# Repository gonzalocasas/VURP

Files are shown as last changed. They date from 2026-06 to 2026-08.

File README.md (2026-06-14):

# 🤖 VURP — Valentin's Ultimate Rover Project

A WiFi-controlled tracked rover, built together by Valentin and Papa.

**Goal:** Learn electronics & coding while building something genuinely cool — a
tank-tread rover you can drive from a phone or laptop browser, with sensors and a
glowing LED ring.

> 🚀 **Start here:** [SETUP.md](SETUP.md) — set up VS Code + PlatformIO and upload
> our first program. Code lives in [src/main.cpp](src/main.cpp).
> The rover web page lives in [data/index.html](data/index.html); upload the
> filesystem image when that file changes.

---

## How it works (the big picture)

```text
   Phone / Laptop  ── WiFi ──►  XIAO ESP32-C3 (the brain)
                                     │
              ┌──── I²C bus (2 wires: SDA + SCL) ────┬──────────┐
              │                  │                   │          │
        Motor FeatherWing   OLED screen        ToF sensor      │
           (0x60)            (0x3C)             (0x29)          │
            │   │           "status/IP"      "wall ahead!"      │
            ▼   ▼                                               │
        Left    Right                              LED ring ◄───┘
        tread   tread   ◄── 2 DC motors           (NeoPixel, on its own pin)
                            (own battery!)

                        GPS module ──► separate UART (serial) pins
```

The ESP32 runs its **own WiFi network** ("VURP") and serves a **web page with an
on-screen joystick**. No app to install — just connect and drive. Steering is
**differential**: run the treads at different speeds to turn, opposite directions
to spin in place.

**Why this layout:** the XIAO ESP32-C3 has very few pins, so we put the motor
driver + OLED + ToF sensor all on the shared **I²C bus** (just 2 pins for all three).
That keeps pins free and is a great lesson in how I²C addresses work.

---

## Parts list (BOM)

| Part | What it does | Status |
| --- | --- | --- |
| **XIAO ESP32-C3** | The brain + WiFi | ✅ Chosen |
| **Adafruit Motor FeatherWing** (DC + Stepper, I²C/TB6612) | Drives the 2 tread motors over I²C (only 2 pins!) | ✅ Chosen |
| **Tracked chassis** (tank treads + 2 DC motors) | Locomotion | ❓ Confirm we have one |
| **LED ring** (NeoPixel / WS2812) | Lights & status display | ✅ Have it |
| **ToF distance sensor** (VL53L0X-type, I²C) | Obstacle detection — phase 1 sensor | ✅ Have it |
| **Tiny OLED screen** (I²C) | Shows WiFi IP, speed, distance | ✅ Have it |
| **Ultrasonic** (HC-SR04) | Backup distance sensor — needs 5V + divider | 🟡 Later |
| **u-blox GPS** (UART) | Outdoor position logging | 🟡 Stretch |
| **Camera** (B0068 etc.) | FPV video — needs the full Raspberry Pi | 🔴 Season 2 |
| **Battery — logic** (for the XIAO, via USB power bank or regulator) | Powers the brain | ❓ Confirm |
| **Battery — motors** (4×AA or LiPo, into FeatherWing terminals) | Powers the treads, **separate from logic** | ❓ Confirm |
| **Header wires + soldering** | To connect XIAO ↔ FeatherWing (it's not a stack) | ❓ Need to solder |
| **Breadboard + jumper wires** | Wiring it all up | ❓ Confirm |
| **On/off switch** | So we're not pulling batteries constantly | nice-to-have |

> ⚠️ **Key rule:** a microcontroller pin can't drive a motor directly — it needs a
> **motor driver** in between. And motors get their **own** battery power, never
> through the microcontroller's pins.

---

## The plan (milestones)

We'll build in small wins so Valentin sees progress every session:

- [x] **1. Blink** — ✅ board boots & uploads, "Hello from VURP!" on Serial. (LED wiring next session.)
- [x] **2. Light up** — ✅ NeoPixel ring runs a rotating rainbow (powered from 3V3, data on D2).
- [x] **3. WiFi page** — ✅ ESP32 serves a web page; a button on the phone turns the ring on/off.
- [x] **4. Motor test** — ✅ spun the M3/M4 treads forward/back from the web page.
- [x] **5. Two motors** — ✅ both treads: drive forward, back, and turn (spin in place).
- [x] **6. Joystick** — ✅ on-screen touch joystick → smooth proportional driving from the phone.
- [x] **7. Screen** — ✅ OLED on the shared I²C bus shows the WiFi name, IP, and live status.
- [ ] **8. Sensors** — read the ToF distance; flash the ring red and stop when close to an obstacle. 👉 **next**
- [ ] **9. Polish** — mount everything on the chassis, tidy wiring, name it, show it off.
- [ ] **Stretch:** GPS logging outdoors; then the full Raspberry Pi + camera for FPV driving.

---

## Decisions made

- ✅ **Brain:** XIAO ESP32-C3 (WiFi, hosts its own web page).
- ✅ **Motor driver:** Adafruit Motor FeatherWing over I²C — beats the L298N here
  because it saves precious GPIO pins and is far more efficient.
- ✅ **Phase-1 sensors:** ToF distance + OLED screen (both I²C). Ultrasonic, GPS,
  and cameras come later.
- ✅ **Language & tools:** Arduino C++, written in **VS Code + PlatformIO**.
- ℹ️ **Note:** the XIAO ESP32-C3 has **no user-programmable onboard LED** (unlike
  most XIAO boards) — so "Blink" uses an **external LED** on a breadboard.

- ✅ **Chassis:** confirmed — tracked chassis with 2 DC motors on hand.
- ✅ **FeatherWing wired:** the ~4 connection wires to the XIAO are soldered.
- ✅ **I²C pins:** on the XIAO ESP32-C3, **SDA = D4 / GPIO6** and
  **SCL = D5 / GPIO7**. The Motor FeatherWing uses address **0x60**.

## Decisions still open

- [ ] **Power:** how we power logic vs. motors (two separate supplies).

---

## Project log

- **2026-06-02** — Project kicked off. Chose wireless web control + ESP32 brain.
  Locked in: XIAO ESP32-C3 + Adafruit Motor FeatherWing (I²C), with ToF + OLED as
  phase-1 sensors. Set up this repo (VS Code + PlatformIO).
- **2026-06-02** — ✅ **Milestone 1 (software half):** first upload working,
  "Hello from VURP!" on the Serial Monitor. The C3 wasn't detected at first; fixed
  by forcing USB download mode (**hold B, tap R, release B**) — good trick to
  remember if the port ever vanishes. LED wiring still to do.
- **2026-06-03** — ✅ **Milestone 1 done** (LED blinks) and ✅ **Milestone 2 done**
  (NeoPixel rainbow, powered from 3V3, data on D2). Confirmed we have the tracked
  chassis and the Motor FeatherWing wires are soldered. **Next session: Friday
  Jun 5 — Milestone 3 (WiFi control page).**
- **2026-06-05** — ✅ **Milestone 3 done**: the XIAO ESP32-C3 creates the **VURP**
  WiFi network and serves a phone-friendly page at **http://192.168.4.1/**. The
  button turns the NeoPixel ring rainbow on/off.
- **2026-06-05** — **Milestone 4 test firmware prepared**: added the Adafruit
  Motor FeatherWing library and web buttons for **M3/M4 forward / stop / reverse**.
  First tests use low speed and auto-stop after 1 second.
- **2026-06-05** — Refactored the rover web controls: HTML moved to
  **data/index.html**, and buttons now call tiny JSON API endpoints instead of
  refreshing the whole page.
- **2026-06-05** — Improved the motor test controls: added low/medium/max speed
  buttons and a short full-power start boost so the tank treads can overcome
  static friction more reliably.
- **2026-06-05** — Replaced the main motor test buttons with a 4-way drive pad:
  forward/back drive both treads, left/right spin in place by running M3 and M4
  in opposite directions.
- **2026-06-14** — ✅ **Milestones 4, 5 & 6 done**: motor test, two-tread driving,
  and now a real **on-screen joystick** (`/api/drive`). The page sends a stick
  vector and the firmware does the differential-drive mixing (`left = y + x`,
  `right = y - x`) into proportional tread speeds. Added a **deadman watchdog**:
  the rover stops itself if the phone stops sending updates (lock / out of range).
  Built, uploaded (firmware + LittleFS), and tested on the rover — drives great.
  **Next: Milestone 7 — wire the OLED onto the I²C bus and show IP + status.**
- **2026-06-14** — ✅ **Milestone 7 done**: wired the **OLED** onto the shared I²C
  bus (no soldering — piggybacks on SDA/SCL alongside the FeatherWing). Boot now
  runs a full **I²C scan** that names each device; it found `0x3C` (OLED), `0x60`
  + `0x70` (the FeatherWing's PCA9685, which also answers the "All Call" address).
  The screen shows the WiFi name, IP, ring state, speed, and an `idle`/`moving`
  state — and only redraws on change so it never stutters the joystick. Contrast
  set to max for brightness. **Next: Milestone 8 — ToF obstacle sensor.**

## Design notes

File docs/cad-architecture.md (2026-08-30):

# VURP CAD component architecture

The CAD model is composed from typed Python objects rather than passing raw
Rhino geometry between Grasshopper components. Rhino conversion happens only
at the output boundary.

## Core concepts

- `Cutout` describes a reusable cutting operation. The same type represents a
  through-cut or a depth-controlled recess.
- `LowerPlate` owns the host plate, walls, shared fillet, and top reveal.
- `BreadboardMount`, `MotorDriverMount`, and `DisplayMount` own the dimensions
  and behavior needed to integrate their devices into the host plate.
- `UpperMountPattern` and `ChassisMountPattern` are reusable interface
  contracts: they expose hole diameters and centers independently of the part
  that consumes them.
- `PlateAssembly` composes the host and all mounts/patterns in a deterministic
  boolean order.
- `DifferentialMechanismPlatform` consumes `UpperMountPattern` and derives its
  four mating pegs from that shared contract.

## Grasshopper data flow

```text
Lower Plate Definition ─┐
Breadboard Mount ───────┤
Motor Driver Mount ─────┤
Display Mount ──────────┼─> Lower Plate Assembly ─> body + display holder
Upper Mount Pattern ────┤
Chassis Mount Pattern ──┘
          │
          └────────────────> Differential Mechanism Platform
```

Feature components output configuration objects, not Breps. This keeps them
CAD-agnostic, makes validation explicit, and allows downstream parts to reuse
interfaces such as `UpperMountPattern` without copying coordinates.

`build_vurp_lower_plate(PlateParameters)` remains available as a compatibility
wrapper for scripts written against the original flat parameter API.

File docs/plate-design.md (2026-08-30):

# VURP — Parametric Lower Electronics Plate (COMPAS handoff)

## Goal

Write a small Python script using **COMPAS** that generates the first printable structural part for VURP: a top plate that sits on the Black Gladiator's aluminium deck, with front/back skirts descending below the deck, an integrated tilted display cradle, a longitudinal half-breadboard opening, and four mounting holes for a future upper mechanism layer.

Keep the model **fully parametric** and organized as reusable geometry-building functions. Do **not** model the differential mechanism yet.

## Coordinate convention

- `X` = chassis length, **front = +X**
- `Y` = chassis width, left/right
- `Z` = up
- Top surface of the Gladiator metal deck = `Z = 0`
- Main printed plate extends upward from `Z = 0`
- Front/rear walls extend downward into `-Z`

## Important chassis dimension note

DFRobot publishes **193 × 163 × 60 mm** for the *assembled rover*, including tracks, not the footprint of the central aluminium deck. Do **not** use 193 × 163 mm as the plate size.

Make the actual metal-deck dimensions explicit parameters:
```python
plate_length = ...  # measured metal deck length
plate_width  = ...  # measured metal deck width
```

## Main parameters

```python
plate_length          # measured Gladiator metal deck length
plate_width           # measured Gladiator metal deck width
plate_thickness = 8.0

front_wall_height     # downward from deck
rear_wall_height      # downward from deck
wall_thickness        # independent parameter

breadboard_length
breadboard_width
breadboard_clearance  # XY fit clearance
breadboard_offset_x = 0.0
breadboard_offset_y = 0.0

display_width
display_height
display_depth
display_clearance
display_tilt_deg
display_offset_y
display_recess_depth

upper_hole_diameter
upper_hole_x_positions  # two longitudinal positions, symmetric by default
upper_hole_y_offset     # one row on each side of breadboard
```

All dimensions in **mm**.

## Geometry

### 1. Main plate
Rectangular solid matching the central metal deck footprint.

- thickness default: **8 mm**
- lower face at `Z = 0`
- top face at `Z = +plate_thickness`

### 2. Front + rear downward walls
Continuous walls attached to the **front and rear edges only**.

- extend from the plate down into `-Z`
- independent parametric heights
- intended to visually/protectively cover the motor/battery hardware below the aluminium deck
- keep wall thickness parametrizable
- no side walls in this first iteration

Prefer small fillets/chamfers only if they remain robust and easy to print; geometry should work without them.

### 3. Half-breadboard opening
Make a rectangular **through-opening** in the plate, long axis parallel to `X`.

The half-breadboard is **10 mm tall**. Because the plate is 8 mm thick and the breadboard rests on the original metal deck at `Z=0`, it should protrude approximately **2 mm above the printed plate**.

- opening dimensions = breadboard XY dimensions + clearance
- centered by default, but `offset_x/y` must be exposed
- simple rounded corners are optional/parametric

### 4. Four upper-layer mounting holes
Four vertical through-holes in the plate for a future upper electronics/mechanism layer.

- two holes on each side of the breadboard opening
- symmetric by default
- hole diameter parametrizable
- `Y` spacing controlled by `upper_hole_y_offset`
- the two `X` positions controlled explicitly/parametrically
- future layer will plug/screw/standoff into these holes; do not design that layer yet

### 5. Integrated tilted display cradle
At the **front** of the plate, integrate a tilted display support similar to the current VURP concept render.

The display should sit on an inclined planar surface; do **not** rely on the PCB's mounting holes.

Requirements:
- tilt angle parametrizable
- shallow rectangular recess/depression matching the display body/PCB envelope + clearance
- recess prevents lateral sliding
- leave display face exposed
- cradle must blend structurally into the plate/front area rather than being a loose bracket

Also generate an **optional separate bezel/frame** that sits over the perimeter of the display and mechanically traps it in the recess. The bezel can use small screws/snap tabs later; for this iteration, just make its geometry and fit parameters clear. Do not cover the active screen area.

## Script architecture

Prefer simple functions, e.g.:

```python
def make_base_plate(params): ...
def add_front_rear_walls(body, params): ...
def cut_breadboard_opening(body, params): ...
def cut_upper_mount_holes(body, params): ...
def add_display_cradle(body, params): ...
def make_display_bezel(params): ...
def build_vurp_lower_plate(params): ...
```

Return at least:
```python
body
display_bezel  # optional second printable object
```

Use COMPAS geometry/Brep/mesh operations appropriate to the installed version, but keep boolean operations isolated so the backend can be swapped later.

## Print/design assumptions

- Intended for FDM printing, initially on a Bambu A1 Mini.
- Avoid unnecessary decorative geometry.
- Prefer function-driven geometry, sensible clearances, printable overhangs, and serviceability.
- The plate should remain visually clean enough that a later iteration can add a smooth curved outer cover over the exposed electronics.
- Do not add the differential mechanism, upper platform, battery mounts, MCU mounts, or cable routing yet.

## First deliverable

Produce:
1. one self-contained Python script;
2. a clear parameter block at the top;
3. generated COMPAS geometry for the lower plate + optional display bezel;
4. a simple preview/export path (STL preferred, STEP if straightforward);
5. comments marking dimensions that must be measured from the physical Gladiator/display/breadboard before final printing.

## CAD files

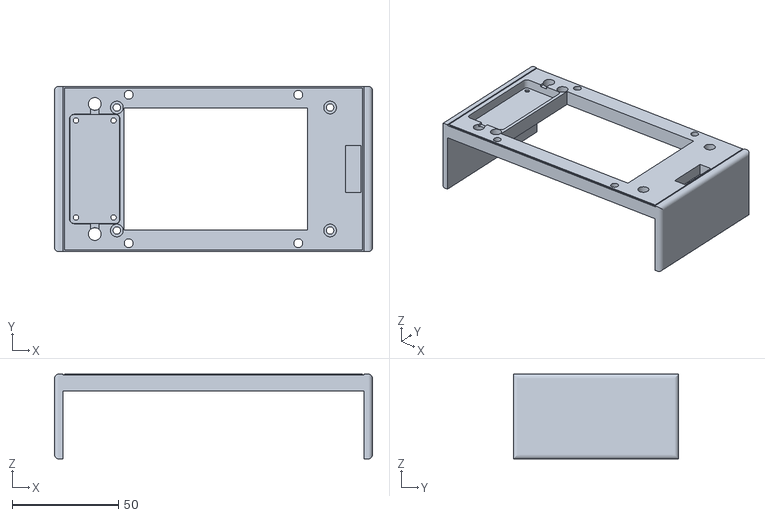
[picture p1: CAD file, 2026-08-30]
design/plate-design.stl
150.0 x 78.0 x 40.0

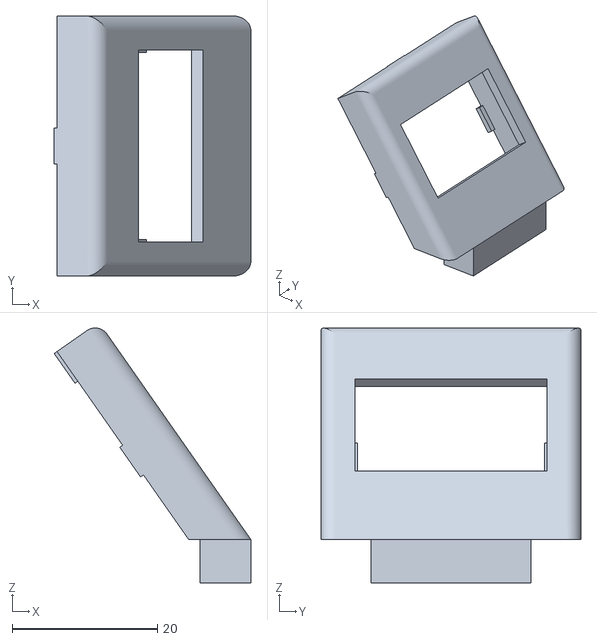
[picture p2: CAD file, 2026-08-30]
design/display-holder.stl
27.1 x 35.8 x 35.1

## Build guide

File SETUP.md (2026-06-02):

# 🛠️ Setting up the workshop (one-time)

We program the rover from **VS Code** using the **PlatformIO** extension. Do these
steps together with Valentin — he can do the clicking. You only do this **once**.

## 1. Install the PlatformIO extension

1. Open **VS Code**.
2. Click the **Extensions** icon in the left sidebar (the four little squares).
3. Search for **"PlatformIO IDE"** and click **Install**.
4. Wait for it to finish setting up (it downloads some tools — grab a snack ☕).
   When it's ready you'll see a little **alien/ant head 👽 icon** in the left sidebar.

> PlatformIO will download the ESP32 toolchain the first time we build — that's
> normal and only happens once.

## 2. Open the firmware project

1. In VS Code: **File → Open Folder…** and choose the **`VURP`** project folder
   (the one with `platformio.ini` and `README.md` inside).
2. PlatformIO reads `platformio.ini` and already knows our board is the
   **Seeed XIAO ESP32-C3**. Nothing to configure. 🎉

## 3. Plug in the board

1. Connect the **XIAO ESP32-C3** to the Mac with a **USB-C data cable**.
   ⚠️ Some cheap cables are *charge-only* and won't work — if the board is never
   found, **try a different cable first**.

## 4. Upload our first program

At the **bottom blue bar** of VS Code, PlatformIO adds little buttons:

- **✓ (checkmark)** = Build (compile the code)
- **→ (arrow)** = Upload (send it to the board)
- **🔌 (plug)** = Serial Monitor (see messages from the board)

Steps:

1. Click **→ (Upload)**. First time it compiles a lot — be patient.
2. Click the **🔌 (Serial Monitor)**.
3. 🎉 You should see **"Hello from VURP! :)"** and then `LED on` / `LED off`
   scrolling. The toolchain works!

> 💡 If upload fails: unplug/replug, try a different USB-C cable. The port is
> auto-detected, but you can force it in `platformio.ini` with `upload_port`.
> If it's really stubborn: hold **BOOT**, tap **RESET**, release **BOOT**, then upload.

## 5. (Same session) Wire the LED

Now make the blink real. On a breadboard:

```text
  XIAO D10 --> [220 ohm resistor] --> LED long leg (+)
                                      LED short leg (-) --> XIAO GND
```

- The **resistor** protects the LED — never skip it.
- LED **long leg = +**, **short leg = -**.
- The LED should blink once per second, matching `LED on` / `LED off`. ✅

That's Milestone 1 done — the board is alive and Valentin built his first circuit.
Next up: **Milestone 2 — light up the NeoPixel ring.**

---

### How the project is organized

```text
VURP/                <- open THIS folder in VS Code
  platformio.ini     <- project settings (board, libraries)
  src/
    main.cpp         <- the program that runs on the rover
  README.md          <- the master plan
  SETUP.md           <- this guide
```

As we add milestones, the code in `src/main.cpp` grows, and any libraries we need
get listed in `platformio.ini` (PlatformIO downloads them automatically).

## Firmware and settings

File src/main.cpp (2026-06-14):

/*
 * VURP — Milestone 7: "Status screen"
 * ---------------------------------------
 * The XIAO ESP32-C3 creates its own WiFi network. The web page can turn the
 * NeoPixel ring on/off, drive the rover with an on-screen joystick (smooth,
 * proportional differential steering), and still test the two motors one at a
 * time. A little I2C OLED now shows the WiFi name, IP, and live status — no need
 * for the Serial Monitor to find the rover.
 *
 * Board: Seeed XIAO ESP32-C3   |   Tools: VS Code + PlatformIO
 *
 * WIRING:
 *
 *     Ring  VCC / "+"          -->  XIAO  3V3 pin
 *     Ring  GND / "-"          -->  XIAO  GND pin
 *     Ring  DIN (data INPUT)   -->  XIAO  D2
 *
 *     FeatherWing SDA          -->  XIAO  D4 / SDA / GPIO6
 *     FeatherWing SCL          -->  XIAO  D5 / SCL / GPIO7
 *     FeatherWing GND          -->  XIAO  GND
 *     FeatherWing logic power  -->  XIAO  3V3
 *     FeatherWing motor power  -->  separate motor battery terminals
 *
 *     Left/right motors        -->  FeatherWing M3 and M4
 *
 * Connect from the phone:
 *
 *     WiFi network: VURP
 *     Password:     letitroll
 *     Web page:     http://192.168.4.1/
 */

#include <Arduino.h>
#include <Adafruit_GFX.h>
#include <Adafruit_MotorShield.h>
#include <Adafruit_NeoPixel.h>
#include <Adafruit_SSD1306.h>
#include <LittleFS.h>
#include <WebServer.h>
#include <WiFi.h>
#include <Wire.h>

#define LED_PIN     D2
#define NUM_PIXELS  16
#define BRIGHTNESS  40

#define SCREEN_WIDTH   128
#define SCREEN_HEIGHT  64
const uint8_t OLED_ADDRESS = 0x3C;
const unsigned long OLED_REFRESH_MS = 500;  // How often we check if the screen needs redrawing.

const char *WIFI_NAME = "VURP";
const char *WIFI_PASSWORD = "letitroll";

const uint8_t MOTOR_FEATHERWING_ADDRESS = 0x60;
const uint8_t LEFT_MOTOR_PORT = 3;
const uint8_t RIGHT_MOTOR_PORT = 4;
const uint8_t DEFAULT_MOTOR_SPEED = 210;  // 0..255. Tank treads need more torque than free wheels.
const uint8_t START_BOOST_SPEED = 255;    // Short kick to overcome static friction.
const unsigned long START_BOOST_MS = 180;
const unsigned long MOTOR_TEST_MS = 1500; // Safety: forward/reverse auto-stop after 1.5 seconds.

// Joystick driving (the /api/drive endpoint).
const int DRIVE_DEADBAND = 8;             // Tiny stick wobble near the centre = stop, don't whine.
const uint8_t MIN_MOVE_SPEED = 150;       // Just enough power to actually get the treads rolling.
const unsigned long DRIVE_WATCHDOG_MS = 400; // Deadman: stop if the phone goes quiet (lock/out of range).

Adafruit_NeoPixel ring(NUM_PIXELS, LED_PIN, NEO_GRB + NEO_KHZ800);
Adafruit_MotorShield motorShield(MOTOR_FEATHERWING_ADDRESS);
Adafruit_DCMotor *leftMotor = nullptr;
Adafruit_DCMotor *rightMotor = nullptr;
Adafruit_SSD1306 oled(SCREEN_WIDTH, SCREEN_HEIGHT, &Wire, -1);
WebServer server(80);

bool ringIsOn = false;
bool motorDriverFound = false;
bool oledFound = false;
String roverIp = "?";          // filled in once WiFi is up, then shown on the OLED.
String lastOledKey = "";       // what's currently on the screen, so we only redraw on change.
unsigned long lastOledCheck = 0;
String motorStatus = "motor ready?";
uint8_t motorSpeed = DEFAULT_MOTOR_SPEED;
uint16_t hueOffset = 0;
unsigned long lastAnimationFrame = 0;
unsigned long motorStopAt = 0;
unsigned long motorBoostEndsAt = 0;
unsigned long driveWatchdogAt = 0;
bool leftMotorActive = false;
bool rightMotorActive = false;

String ringStatusText() {
  return ringIsOn ? "ON" : "OFF";
}

void showRingOff() {
  ring.clear();
  ring.show();
}

void showRainbowFrame() {
  for (int i = 0; i < NUM_PIXELS; i++) {
    uint16_t hue = hueOffset + (i * 65536L / NUM_PIXELS);
    ring.setPixelColor(i, ring.gamma32(ring.ColorHSV(hue)));
  }

  ring.show();
  hueOffset += 256;
}

void stopMotor(Adafruit_DCMotor *motor) {
  if (motor != nullptr) {
    motor->run(RELEASE);
  }
}

void stopAllMotors() {
  stopMotor(leftMotor);
  stopMotor(rightMotor);

  motorStopAt = 0;
  motorBoostEndsAt = 0;
  driveWatchdogAt = 0;
  leftMotorActive = false;
  rightMotorActive = false;
  motorStatus = "stopped";
  Serial.println("Motors stopped");
}

// Drive one tread at a signed speed: positive = forward, negative = reverse,
// zero = coast to a stop. Used by the joystick (proportional) driving.
void setTread(Adafruit_DCMotor *motor, int signedSpeed) {
  if (motor == nullptr) {
    return;
  }

  if (signedSpeed == 0) {
    motor->run(RELEASE);
    return;
  }

  motor->setSpeed((uint8_t)constrain(abs(signedSpeed), 0, 255));
  motor->run(signedSpeed > 0 ? FORWARD : BACKWARD);
}

// Turn a joystick axis amount (-100..100) into a signed tread speed. Below the
// deadband the tread stops; above it we map smoothly up to the current top speed,
// starting at MIN_MOVE_SPEED so the treads actually move instead of just buzzing.
int treadSpeedFromInput(int input) {
  int magnitude = abs(input);

  if (magnitude < DRIVE_DEADBAND) {
    return 0;
  }

  int topSpeed = motorSpeed;
  int minSpeed = min((int)MIN_MOVE_SPEED, topSpeed);
  int speed = constrain(map(magnitude, DRIVE_DEADBAND, 100, minSpeed, topSpeed), 0, 255);

  return input > 0 ? speed : -speed;
}

void startMotorWithBoost(Adafruit_DCMotor *motor, uint8_t direction) {
  motor->setSpeed(START_BOOST_SPEED);
  motor->run(direction);
  motorBoostEndsAt = millis() + START_BOOST_MS;
}

void applyCruiseSpeed() {
  if (leftMotorActive && leftMotor != nullptr) {
    leftMotor->setSpeed(motorSpeed);
  }

  if (rightMotorActive && rightMotor != nullptr) {
    rightMotor->setSpeed(motorSpeed);
  }

  motorBoostEndsAt = 0;
}

void runMotor(Adafruit_DCMotor *motor, const char *motorName, uint8_t direction, const char *label) {
  if (!motorDriverFound || motor == nullptr) {
    motorStatus = "driver not found";
    Serial.println("Cannot run motor: Motor FeatherWing was not found on I2C.");
    return;
  }

  stopAllMotors();
  startMotorWithBoost(motor, direction);
  leftMotorActive = motor == leftMotor;
  rightMotorActive = motor == rightMotor;
  motorStopAt = millis() + MOTOR_TEST_MS;
  motorStatus = String(motorName) + " " + label + " at speed " + motorSpeed;

  Serial.print(motorName);
  Serial.print(" ");
  Serial.print(label);
  Serial.print(" at speed ");
  Serial.print(motorSpeed);
  Serial.println(" with start boost");
}

void runBothMotors(uint8_t direction, const char *label) {
  if (!motorDriverFound || leftMotor == nullptr || rightMotor == nullptr) {
    motorStatus = "driver not found";
    Serial.println("Cannot run motors: Motor FeatherWing was not found on I2C.");
    return;
  }

  stopAllMotors();
  startMotorWithBoost(leftMotor, direction);
  startMotorWithBoost(rightMotor, direction);
  leftMotorActive = true;
  rightMotorActive = true;
  motorStopAt = millis() + MOTOR_TEST_MS;
  motorStatus = String("both motors ") + label + " at speed " + motorSpeed;

  Serial.print("Both motors ");
  Serial.print(label);
  Serial.print(" at speed ");
  Serial.print(motorSpeed);
  Serial.println(" with start boost");
}

void spinMotors(uint8_t leftDirection, uint8_t rightDirection, const char *label) {
  if (!motorDriverFound || leftMotor == nullptr || rightMotor == nullptr) {
    motorStatus = "driver not found";
    Serial.println("Cannot spin motors: Motor FeatherWing was not found on I2C.");
    return;
  }

  stopAllMotors();
  startMotorWithBoost(leftMotor, leftDirection);
  startMotorWithBoost(rightMotor, rightDirection);
  leftMotorActive = true;
  rightMotorActive = true;
  motorStopAt = millis() + MOTOR_TEST_MS;
  motorStatus = String("spin ") + label + " at speed " + motorSpeed;

  Serial.print("Spin ");
  Serial.print(label);
  Serial.print(" at speed ");
  Serial.print(motorSpeed);
  Serial.println(" with start boost");
}

String jsonEscape(const String &value) {
  String escaped;

  for (size_t i = 0; i < value.length(); i++) {
    char c = value[i];

    if (c == '"' || c == '\\') {
      escaped += '\\';
    }

    escaped += c;
  }

  return escaped;
}

String statusJson() {
  return String("{") +
    "\"ringOn\":" + (ringIsOn ? "true" : "false") + "," +
    "\"motorDriverFound\":" + (motorDriverFound ? "true" : "false") + "," +
    "\"motorStatus\":\"" + jsonEscape(motorStatus) + "\"," +
    "\"motorSpeed\":" + String(motorSpeed) + "," +
    "\"startBoostSpeed\":" + String(START_BOOST_SPEED) + "," +
    "\"startBoostMs\":" + String(START_BOOST_MS) + "," +
    "\"motorPulseMs\":" + String(MOTOR_TEST_MS) +
    "}";
}

void sendStatusJson() {
  server.send(200, "application/json", statusJson());
}

String jsonStringValue(const String &body, const String &key) {
  String marker = "\"" + key + "\"";
  int keyIndex = body.indexOf(marker);

  if (keyIndex < 0) {
    return "";
  }

  int colonIndex = body.indexOf(':', keyIndex + marker.length());
  int firstQuote = body.indexOf('"', colonIndex + 1);
  int secondQuote = body.indexOf('"', firstQuote + 1);

  if (colonIndex < 0 || firstQuote < 0 || secondQuote < 0) {
    return "";
  }

  return body.substring(firstQuote + 1, secondQuote);
}

bool jsonBoolValue(const String &body, const String &key, bool fallback) {
  String marker = "\"" + key + "\"";
  int keyIndex = body.indexOf(marker);

  if (keyIndex < 0) {
    return fallback;
  }

  int colonIndex = body.indexOf(':', keyIndex + marker.length());

  if (colonIndex < 0) {
    return fallback;
  }

  String value = body.substring(colonIndex + 1);
  value.trim();
  return value.startsWith("true");
}

int jsonIntValue(const String &body, const String &key, int fallback) {
  String marker = "\"" + key + "\"";
  int keyIndex = body.indexOf(marker);

  if (keyIndex < 0) {
    return fallback;
  }

  int colonIndex = body.indexOf(':', keyIndex + marker.length());

  if (colonIndex < 0) {
    return fallback;
  }

  String value = body.substring(colonIndex + 1);
  value.trim();
  return value.toInt();
}

void handleHome() {
  File indexFile = LittleFS.open("/index.html", "r");

  if (!indexFile) {
    server.send(500, "text/plain", "Missing /index.html. Upload the LittleFS filesystem image.");
    return;
  }

  server.streamFile(indexFile, "text/html");
  indexFile.close();
}

void handleApiRing() {
  ringIsOn = jsonBoolValue(server.arg("plain"), "on", !ringIsOn);
  Serial.print("Ring is now ");
  Serial.println(ringStatusText());

  if (!ringIsOn) {
    showRingOff();
  }

  sendStatusJson();
}

void handleApiMotor() {
  String command = jsonStringValue(server.arg("plain"), "cmd");

  if (command == "both_forward") {
    runBothMotors(FORWARD, "forward");
  } else if (command == "both_reverse") {
    runBothMotors(BACKWARD, "reverse");
  } else if (command == "spin_left") {
    spinMotors(BACKWARD, FORWARD, "left");
  } else if (command == "spin_right") {
    spinMotors(FORWARD, BACKWARD, "right");
  } else if (command == "m3_forward") {
    runMotor(leftMotor, "M3", FORWARD, "forward");
  } else if (command == "m3_reverse") {
    runMotor(leftMotor, "M3", BACKWARD, "reverse");
  } else if (command == "m4_forward") {
    runMotor(rightMotor, "M4", FORWARD, "forward");
  } else if (command == "m4_reverse") {
    runMotor(rightMotor, "M4", BACKWARD, "reverse");
  } else {
    stopAllMotors();
  }

  sendStatusJson();
}

void handleApiDrive() {
  if (!motorDriverFound || leftMotor == nullptr || rightMotor == nullptr) {
    motorStatus = "driver not found";
    sendStatusJson();
    return;
  }

  String body = server.arg("plain");
  int x = constrain(jsonIntValue(body, "x", 0), -100, 100);  // turn: + = right
  int y = constrain(jsonIntValue(body, "y", 0), -100, 100);  // throttle: + = forward

  // Differential-drive mixing: combine throttle and turn into a speed per tread.
  int left = y + x;
  int right = y - x;

  // Mixing can push a tread past 100; scale both back together so we keep the
  // turn ratio instead of just clipping one side.
  int largest = max(abs(left), abs(right));
  if (largest > 100) {
    left = left * 100 / largest;
    right = right * 100 / largest;
  }

  int leftSpeed = treadSpeedFromInput(left);
  int rightSpeed = treadSpeedFromInput(right);

  setTread(leftMotor, leftSpeed);
  setTread(rightMotor, rightSpeed);

  // Joystick mode owns the motors now: drop the discrete-test timers and arm the
  // deadman watchdog instead so a quiet phone stops the rover.
  motorStopAt = 0;
  motorBoostEndsAt = 0;
  leftMotorActive = leftSpeed != 0;
  rightMotorActive = rightSpeed != 0;

  if (leftSpeed == 0 && rightSpeed == 0) {
    driveWatchdogAt = 0;
    motorStatus = "centered";
  } else {
    driveWatchdogAt = millis() + DRIVE_WATCHDOG_MS;
    motorStatus = String("drive L") + leftSpeed + " R" + rightSpeed;
  }

  sendStatusJson();
}

void handleApiSpeed() {
  int requestedSpeed = jsonIntValue(server.arg("plain"), "speed", motorSpeed);
  motorSpeed = (uint8_t)constrain(requestedSpeed, 80, 255);
  motorStatus = String("speed set to ") + motorSpeed;

  if (motorStopAt > 0 && motorBoostEndsAt == 0) {
    applyCruiseSpeed();
  }

  Serial.print("Motor speed set to ");
  Serial.println(motorSpeed);

  sendStatusJson();
}

void handleLegacyToggleRing() {
  ringIsOn = !ringIsOn;
  Serial.print("Ring is now ");
  Serial.println(ringStatusText());

  if (!ringIsOn) {
    showRingOff();
  }

  sendStatusJson();
}

void handleLegacyMotor() {
  String command = server.arg("cmd");

  if (command == "both_forward") {
    runBothMotors(FORWARD, "forward");
  } else if (command == "both_reverse") {
    runBothMotors(BACKWARD, "reverse");
  } else if (command == "spin_left") {
    spinMotors(BACKWARD, FORWARD, "left");
  } else if (command == "spin_right") {
    spinMotors(FORWARD, BACKWARD, "right");
  } else if (command == "m3_forward") {
    runMotor(leftMotor, "M3", FORWARD, "forward");
  } else if (command == "m3_reverse") {
    runMotor(leftMotor, "M3", BACKWARD, "reverse");
  } else if (command == "m4_forward") {
    runMotor(rightMotor, "M4", FORWARD, "forward");
  } else if (command == "m4_reverse") {
    runMotor(rightMotor, "M4", BACKWARD, "reverse");
  } else {
    stopAllMotors();
  }

  sendStatusJson();
}

void handleFavicon() {
  server.send(204, "text/plain", "");
}

void handleNotFound() {
  Serial.print("No web handler for ");
  Serial.print(server.method() == HTTP_GET ? "GET " : "POST ");
  Serial.println(server.uri());

  server.send(404, "text/plain", "VURP does not have that page.");
}

bool probeI2cAddress(uint8_t address) {
  Wire.setTimeOut(50);

  Serial.print("Checking I2C address 0x");
  if (address < 16) {
    Serial.print("0");
  }
  Serial.print(address, HEX);
  Serial.print(" ... ");

  Wire.beginTransmission(address);
  uint8_t error = Wire.endTransmission();

  if (error == 0) {
    Serial.println("FOUND");
    return true;
  }

  Serial.print("not found, error ");
  Serial.println(error);
  return false;
}

// Friendly name for the I2C addresses we expect on the VURP bus, so the scan
// below reads like a parts list instead of a wall of hex numbers.
const char *i2cDeviceName(uint8_t address) {
  switch (address) {
    case 0x60: return "Motor FeatherWing";
    case 0x3C: return "OLED screen";
    case 0x29: return "ToF distance sensor";
    default:   return "unknown device";
  }
}

// Walk every I2C address and print whatever answers. Great for "wire it up and
// see if it shows up" — a freshly wired OLED should appear here at 0x3C.
void scanI2cBus() {
  Serial.println("Scanning the I2C bus for devices...");
  int found = 0;

  for (uint8_t address = 0x01; address < 0x7F; address++) {
    Wire.beginTransmission(address);
    if (Wire.endTransmission() == 0) {
      found++;
      Serial.print("  found 0x");
      if (address < 16) {
        Serial.print("0");
      }
      Serial.print(address, HEX);
      Serial.print("  <- ");
      Serial.println(i2cDeviceName(address));
    }
  }

  if (found == 0) {
    Serial.println("  ...nothing answered. Check the SDA/SCL/3V3/GND wiring.");
  } else {
    Serial.print("I2C scan done: ");
    Serial.print(found);
    Serial.println(" device(s).");
  }
}

void setupMotorDriver() {
  Wire.begin(SDA, SCL);

  Serial.print("I2C SDA pin: GPIO");
  Serial.print(SDA);
  Serial.print(" / D4, SCL pin: GPIO");
  Serial.print(SCL);
  Serial.println(" / D5");

  scanI2cBus();
  probeI2cAddress(MOTOR_FEATHERWING_ADDRESS);

  motorDriverFound = motorShield.begin();

  if (!motorDriverFound) {
    motorStatus = "driver not found";
    Serial.println("Could not find Motor FeatherWing at I2C address 0x60.");
    return;
  }

  leftMotor = motorShield.getMotor(LEFT_MOTOR_PORT);
  rightMotor = motorShield.getMotor(RIGHT_MOTOR_PORT);
  stopAllMotors();
  motorStatus = "ready on M3 and M4";
  Serial.println("Motor FeatherWing found. Ready to test M3 and M4.");
}

void setupOled() {
  // Shares the I2C bus already started by setupMotorDriver().
  oledFound = oled.begin(SSD1306_SWITCHCAPVCC, OLED_ADDRESS);

  if (!oledFound) {
    Serial.println("OLED not found at 0x3C. Check wiring (or it may be an SH1106).");
    return;
  }

  // Crank the contrast register to its maximum so the screen is as bright as it goes.
  oled.ssd1306_command(SSD1306_SETCONTRAST);
  oled.ssd1306_command(0xFF);

  oled.clearDisplay();
  oled.setTextColor(SSD1306_WHITE);
  oled.display();
  Serial.println("OLED ready (max brightness).");
}

// One coarse word for how the rover is moving. We deliberately keep this simple
// (not the live L/R speeds) so the screen only redraws on real changes, never
// mid-drive — that keeps the joystick feeling snappy.
const char *motionWord() {
  return (leftMotorActive || rightMotorActive) ? "moving" : "idle";
}

// A short signature of everything shown on screen. If it hasn't changed, there's
// no reason to redraw.
String oledStateKey() {
  return roverIp + "|" + (ringIsOn ? "1" : "0") + "|" + motorSpeed + "|" + motionWord();
}

void drawOledStatus() {
  if (!oledFound) {
    return;
  }

  oled.clearDisplay();

  oled.setTextSize(2);
  oled.setCursor(0, 0);
  oled.println("VURP");

  oled.setTextSize(1);
  oled.setCursor(0, 20);
  oled.print("net: ");
  oled.println(WIFI_NAME);
  oled.print("ip:  ");
  oled.println(roverIp);
  oled.print("ring:");
  oled.print(ringIsOn ? "ON " : "OFF");
  oled.print("  spd:");
  oled.println(motorSpeed);
  oled.print("state: ");
  oled.println(motionWord());

  oled.display();
}

// Redraw the screen when its contents change (checked a couple of times a second).
void updateOled() {
  if (!oledFound || millis() - lastOledCheck < OLED_REFRESH_MS) {
    return;
  }

  lastOledCheck = millis();
  String key = oledStateKey();

  if (key != lastOledKey) {
    lastOledKey = key;
    drawOledStatus();
  }
}

void setup() {
  Serial.begin(115200);
  delay(1000);

  ring.begin();
  ring.setBrightness(BRIGHTNESS);
  showRingOff();

  Serial.println("Hello from VURP! Starting WiFi motor test page...");

  if (!LittleFS.begin()) {
    Serial.println("LittleFS failed to mount. Upload the filesystem image for data/index.html.");
  } else if (!LittleFS.exists("/index.html")) {
    Serial.println("LittleFS mounted, but /index.html is missing.");
  } else {
    Serial.println("LittleFS mounted. Web page file found.");
  }

  setupMotorDriver();
  setupOled();

  WiFi.mode(WIFI_AP);
  WiFi.softAP(WIFI_NAME, WIFI_PASSWORD);

  IPAddress ip = WiFi.softAPIP();
  roverIp = ip.toString();
  Serial.print("Connect to WiFi network: ");
  Serial.println(WIFI_NAME);
  Serial.print("Password: ");
  Serial.println(WIFI_PASSWORD);
  Serial.print("Open this page: http://");
  Serial.println(ip);

  drawOledStatus();   // first paint now that we know the IP

  server.on("/", HTTP_GET, handleHome);
  server.on("/api/status", HTTP_GET, sendStatusJson);
  server.on("/api/ring", HTTP_POST, handleApiRing);
  server.on("/api/motor", HTTP_POST, handleApiMotor);
  server.on("/api/drive", HTTP_POST, handleApiDrive);
  server.on("/api/speed", HTTP_POST, handleApiSpeed);
  server.on("/toggle-ring", HTTP_POST, handleLegacyToggleRing);
  server.on("/toggle", HTTP_POST, handleLegacyToggleRing);
  server.on("/motor", HTTP_POST, handleLegacyMotor);
  server.on("/favicon.ico", HTTP_GET, handleFavicon);
  server.onNotFound(handleNotFound);
  server.begin();
}

void loop() {
  server.handleClient();

  if (ringIsOn && millis() - lastAnimationFrame >= 20) {
    lastAnimationFrame = millis();
    showRainbowFrame();
  }

  if (motorBoostEndsAt > 0 && millis() >= motorBoostEndsAt) {
    applyCruiseSpeed();
  }

  if (motorStopAt > 0 && millis() >= motorStopAt) {
    stopAllMotors();
  }

  // Deadman: if the joystick has gone quiet, stop so a locked phone or a
  // dropped WiFi connection can't leave the rover driving off on its own.
  if (driveWatchdogAt > 0 && millis() >= driveWatchdogAt) {
    Serial.println("Drive watchdog: no joystick update, stopping.");
    stopAllMotors();
  }

  updateOled();
}

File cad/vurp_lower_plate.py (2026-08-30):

"""Parametric lower electronics plate for VURP.

The geometry layer deliberately imports only COMPAS.  It does not import Rhino,
Grasshopper, or a CAD-specific boolean kernel.  A COMPAS Brep backend must be
available at runtime (Rhino is used by ``rhino_preview.py``).

Coordinate system: front = +X, left/right = Y, up = +Z, metal deck top = Z 0.
All dimensions are millimetres.
"""

from dataclasses import dataclass, field
from math import cos, pi, radians, sin, tan
from typing import Dict, Iterable, List, Optional, Tuple

from compas.datastructures import Mesh
from compas.files import STL
from compas.geometry import Box, Brep, Cylinder, Frame, NurbsCurve, Point, Vector


# Concrete Brep implementation. CAD adapters may replace this with (for
# example) compas_rhino.geometry.RhinoBrep without leaking Rhino imports here.
BREP_BACKEND = Brep


def set_brep_backend(backend) -> None:
    """Inject a COMPAS-compatible Brep implementation."""
    global BREP_BACKEND
    BREP_BACKEND = backend


@dataclass
class PlateParameters:
    # ---------------------------------------------------------------------
    # MEASURE BEFORE PRINTING.  These are conservative preview placeholders,
    # NOT DFRobot's published 193 x 163 mm assembled-rover envelope.
    plate_length: float = 145.0
    plate_width: float = 105.0
    # ---------------------------------------------------------------------
    plate_thickness: float = 8.0
    front_wall_height: float = 35.0
    rear_wall_height: float = 28.0
    wall_thickness: float = 4.0
    fillet_radius: float = 2.0

    # MEASURE the actual half breadboard (including clips/lips).
    breadboard_length: float = 82.5
    breadboard_width: float = 47.0
    breadboard_clearance: float = 0.6  # total XY clearance, not per side
    breadboard_offset_x: float = 0.0
    breadboard_offset_y: float = 0.0

    # Adafruit Motor FeatherWing PCB outline (product 2927). Only the X
    # placement is intended as a Grasshopper control in this iteration.
    motor_driver_offset_x: float = -55.0
    motor_driver_length: float = 50.8  # long axis, oriented along global Y
    motor_driver_width: float = 22.9
    motor_driver_clearance: float = 0.6  # total XY clearance
    motor_driver_corner_radius: float = 2.5
    # None tracks half the current plate thickness; a supplied value overrides it.
    motor_driver_recess_depth: Optional[float] = None
    motor_driver_mount_hole_diameter: float = 2.54
    motor_driver_mount_hole_spacing_x: float = 17.78
    motor_driver_mount_hole_spacing_y: float = 45.72
    motor_driver_draft_deg: float = 1.5
    motor_driver_counterbore_diameter: float = 5.0
    motor_driver_counterbore_depth: float = 2.0
    motor_driver_cable_hole_diameter: float = 6.0
    motor_driver_cable_channel_width: float = 4.0
    motor_driver_cable_channel_depth: float = 1.2
    top_reveal_width: float = 0.8
    top_reveal_depth: float = 0.5

    # MEASURE the complete display PCB/body and active screen opening.
    display_width: float = 38.0
    display_height: float = 28.0
    display_depth: float = 4.0
    display_active_width: float = 25.0
    display_active_height: float = 14.0
    display_window_offset_y: float = 0.0
    display_clearance: float = 0.5  # total width/height clearance
    display_tilt_deg: float = 55.0  # degrees above horizontal
    display_offset_y: float = 0.0
    display_recess_depth: float = 2.0
    display_support_margin: float = 4.0
    display_support_thickness: float = 5.0
    display_front_overlap: float = 5.0
    display_joint_width: float = 22.0
    display_joint_depth_x: float = 7.0
    display_joint_insertion_depth: float = 6.0
    display_joint_clearance: float = 0.35  # total clearance, not per side
    display_retainer_tab_size: float = 5.0
    display_retainer_overlap: float = 1.0
    display_retainer_thickness: float = 1.0

    upper_hole_diameter: float = 4.2
    upper_hole_x_positions: Tuple[float, float] = (-48.0, 48.0)
    upper_hole_y_offset: float = 36.0

    # Fasteners into the Gladiator metal deck's longitudinal slits. Each
    # front/rear coordinate defines a symmetric left/right pair.
    chassis_hole_diameter: float = 3.5
    chassis_counterbore_diameter: float = 6.5
    chassis_counterbore_depth: float = 2.0
    chassis_rear_hole_x: float = -55.0
    chassis_rear_hole_y_offset: float = 32.0
    chassis_front_hole_x: float = 55.0
    chassis_front_hole_y_offset: float = 32.0

    bezel_border: float = 3.0
    bezel_thickness: float = 2.0
    boolean_epsilon: float = 0.1
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

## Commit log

2026-06-14 Add joystick driving and OLED status screen (milestones 4-7)
    Drive the rover with an on-screen touch joystick: the web page POSTs a
    stick vector to /api/drive and the firmware does differential-drive
    mixing into proportional tread speeds, with a deadband, a minimum-move
    floor, and a deadman watchdog that stops the rover if the phone goes
    quiet. Web UI moved into data/index.html on LittleFS.
    Add a 128x64 SSD1306 OLED on the shared I2C bus showing WiFi name, IP,
    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
2026-08-29 First print draft
    [display-bezel.stl, display-holder.stl, plate-design.stl]
2026-08-30 Second print
    [display-bezel.stl, display-holder.stl, plate-design.stl]
2026-08-30 Third print
    [plate-design.stl]
2026-08-30 Fourth print
    [plate-design.stl]
2026-08-30 Add parametric COMPAS lower plate design
    [plate-design.stl]
2026-08-30 Sixth iteration of the plate and code to generate it
    [display-holder.stl, plate-design.stl]
